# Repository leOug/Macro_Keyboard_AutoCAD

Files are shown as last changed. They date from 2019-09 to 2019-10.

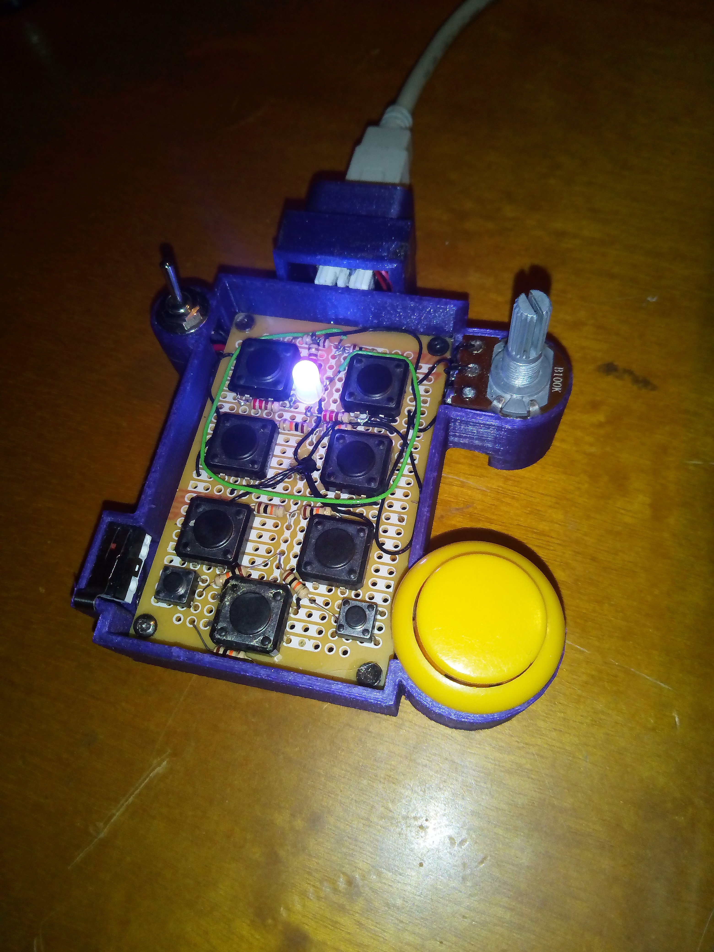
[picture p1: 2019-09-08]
Images/IMG_20190908_190952.jpg

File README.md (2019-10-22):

# Macro_Keyboard_AutoCAD
This is a shortcuts/macro keyboard intended for AutoCAD.

It can be expanded in order to be used with other programs.
I use an Arduino Leonardo Pro Micro ATmega32U4 5V 16MHz with the Keyboard.h library,
in order to send phrases (AutoCAD commands) and press Enter (KEY_RETURN) after a few miliseconds.

Also there is an RGB LED for indicating purposes. The LED can be substitcuted for three extra buttons or potentiometers although
it is rather usefull as it is.

The buttons were chosen for aesthetic and practical purposes. The Arcade button and the Microswitch were chosen for their clickiness
while the toggle switch (selector) is a three terminal one so that is has two modes of operation.

Each Button is connected to GND through a 10K Resistor and to a numbered PIN of the arduino
The toggle switch has three terminals, the left is connected to GND of the Arduino directly, the middle one is connected to a 
numbered arduino PIN and the right one is connected to VCC of the Arduino.

Materials Used:

* 1 x Arduino Leonardo Pro Micro ATmega32U4 5V 16MHz

* 1 x Toggle Switch SPDT ON-ON Mini

* 1 x Arcade Push Button Mini 27mm

* 1 x Microswitch Mini SPDT ON-(ON) - with Roller Simulation (the ones used in 3D printers and CNC machines)

* 2 x Tactile Switch 6x6mm 5mm 4pins

* 7 x Tactile Switch 12x12mm 4.3mm

* 1 x B100K Potentiometer

* 12 x 10KΩhm Resistors for the buttons

* 3 x 220Ωhm Resistors for the LED

* 1 x male micro USB header

* 1 x Female USB type B header

* 1 x perf board

* 4 x M.2 screws

* Super Glue

* Nail Polish for basic water resistance

* Some length of wire

I designed the casing according to the dimensions of the buttons and a vague notion of ergonomics.

You are free to use the design and the code for personal non-commercial usage.

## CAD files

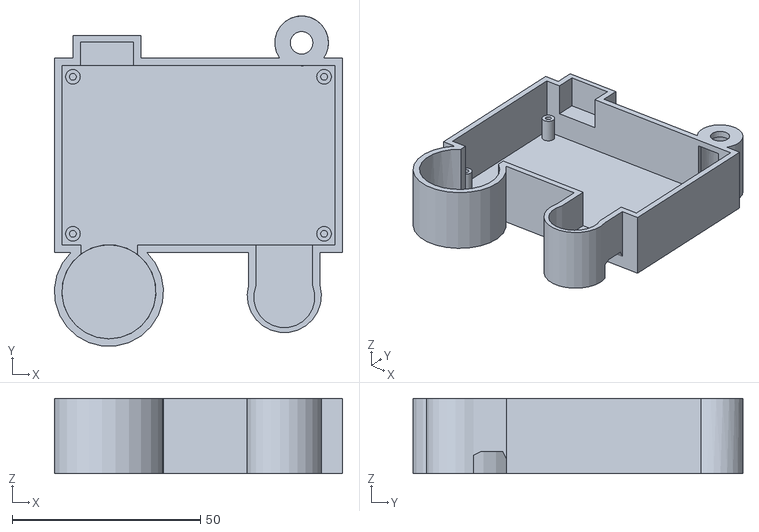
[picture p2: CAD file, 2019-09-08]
CAD/Keyboard.stl
76.5 x 87.6 x 20.0

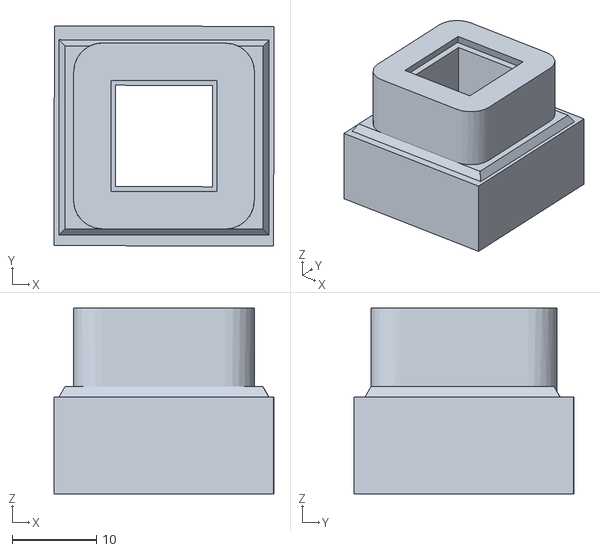
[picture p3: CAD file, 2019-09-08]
CAD/USB.stl
26.0 x 26.0 x 22.0

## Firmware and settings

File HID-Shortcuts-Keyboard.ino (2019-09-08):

#include "Keyboard.h"

#define BUTTON_1 3
#define BUTTON_2 4
#define BUTTON_3 5
#define BUTTON_4 6
#define BUTTON_5 7
#define BUTTON_6 10
#define BUTTON_7 14
#define BUTTON_8 15
#define BUTTON_9 16
#define BUTTON_10 2
#define BUTTON_11 8
int POTENTIOMETER_1 = A0;
int potentiometer_value;
#define SELECTOR_A1 A1
int selector_switch_value = 0; //The selector switch controls the functions of the arcade and the 3d printer buttons

int state = 1; // The initial state of the buttons

// 3 LED pins for the RGB LED, used as a visual indicator
#define LED_1 9
#define LED_2 A2
#define LED_3 A3

void setup()
{
  Serial.begin(9600); // Beging Serial Comunication
  //Define the pinMode for each pin.
  pinMode(2, INPUT);
  pinMode(3, INPUT);
  pinMode(4, INPUT);
  pinMode(5, INPUT);
  pinMode(6, INPUT);
  pinMode(7, INPUT);
  pinMode(8, INPUT);
  pinMode(10, INPUT);
  pinMode(14, INPUT);
  pinMode(15, INPUT);
  pinMode(16, INPUT);
  pinMode(A0, INPUT);
  pinMode(A1, INPUT);
  pinMode(9, OUTPUT);
  pinMode(A2, OUTPUT);
  pinMode(A3, OUTPUT);
  
  

  //Sets the value of the pin on start up.
 
  digitalWrite(BUTTON_1, HIGH);
  digitalWrite(BUTTON_2, HIGH);
  digitalWrite(BUTTON_3, HIGH);
  digitalWrite(BUTTON_4, HIGH);
  digitalWrite(BUTTON_5, HIGH);
  digitalWrite(BUTTON_6, HIGH);
  digitalWrite(BUTTON_7, HIGH);
  digitalWrite(BUTTON_8, HIGH);
  digitalWrite(BUTTON_9, HIGH);
  digitalWrite(POTENTIOMETER_1, HIGH);
  digitalWrite(BUTTON_10, HIGH);
  digitalWrite(BUTTON_11, HIGH);
  digitalWrite(LED_1, LOW);
  digitalWrite(LED_2, LOW);
  digitalWrite(LED_3, LOW);
  
  Keyboard.begin(); //Turns the keyboard input on.
  delay(200); //Wait before continuing on with the code.

}

void loop()

{
  
selector_switch_value = analogRead(SELECTOR_A1);
// If the button is pressed the state variable changes indicating a push
  state = digitalRead(BUTTON_8);
  // The selector switch is treated a potentiometer with two values, 0 and maximum
  // So i put a check for a median value to indicate the open and closing of the switch
  if(state != 1 && selector_switch_value < 500)
  {
    Keyboard.press(KEY_ESC);
    digitalWrite(LED_1, HIGH);
    delay(200);
    digitalWrite(LED_1, LOW);
    delay(50);
    Keyboard.releaseAll();
  }
  else if (state != 1 && selector_switch_value > 500)
  {
    Keyboard.print("qsave");
    digitalWrite(LED_3, HIGH);
    delay(200);
    Keyboard.press(KEY_RETURN);
    digitalWrite(LED_3, LOW);
    delay(50);
    Keyboard.releaseAll();
  }
 state = digitalRead(BUTTON_11);
  if(state != 1 && selector_switch_value < 550)
  {
    Keyboard.press(KEY_RETURN);
    Keyboard.releaseAll();
    digitalWrite(LED_3, HIGH);
    delay(200);
    digitalWrite(LED_3, LOW);
    delay(50);
    ;
  }
  else if (state != 1 && selector_switch_value > 500)
  {
    delay(200);
    Keyboard.press(KEY_DELETE);
    //Keyboard.press(KEY_LEFT_SHIFT);
    //Keyboard.press(KEY_LEFT_GUI);
   digitalWrite(LED_2,HIGH);
    //Keyboard.press(KEY_RETURN);
    Keyboard.releaseAll();
    digitalWrite(LED_2, LOW);
  }
//BEGIN FIRST PRESET
  potentiometer_value = analogRead(POTENTIOMETER_1);
  // The actual potentiometer is used to change between the presets.
  //By reading the potentiometer value (between 15 and 1023 for the B100k) i create 5 distinct "zones"
  //For each zone the 9 push buttons are assigned a function.
  //When the potentiometer is within the boundaries of the assigned zone, the LED changes colour
  if (potentiometer_value < 350 && potentiometer_value > 0) {
  //When the potentiometer is within the boundaries of the assigned zone, the LED changes colour
  digitalWrite(LED_2, LOW);
  digitalWrite(LED_3, HIGH);
  digitalWrite(LED_1, LOW);
  
  state = digitalRead(BUTTON_1);
  if(state != 1 && potentiometer_value < 350 && potentiometer_value>0)
  //FIRST PRESET
  {
  
    Keyboard.print("startcenter");
    delay(100);
    Keyboard.releaseAll();
    Keyboard.print("direction");
    Keyboard.releaseAll();
    delay(50);
    Keyboard.print("arc");
    delay(50);
    Keyboard.press(KEY_RETURN);
    delay(100);
    Keyboard.releaseAll();
  }
//FIRST PRESET
  state = digitalRead(BUTTON_2);
  if(state != 1 && potentiometer_value < 350 && potentiometer_value>0)
  {
    Keyboard.print("circle"); 
    delay(200);
    Keyboard.press(KEY_RETURN);
    delay(200);
    Keyboard.releaseAll();
  }
//FIRST PRESET

  state = digitalRead(BUTTON_3);
  if(state != 1 && potentiometer_value < 350 && potentiometer_value>0)
  {
    Keyboard.print("rectangle"); 
    delay(200);
    Keyboard.releaseAll();
    delay(300);
    Keyboard.press(KEY_RETURN);
    Keyboard.releaseAll();
    
  }
//FIRST PRESET

  state = digitalRead(BUTTON_4);
  if(state != 1 && potentiometer_value < 350 && potentiometer_value>0)
  {
    delay(100);
    Keyboard.print("scale"); 
    Keyboard.press(KEY_RETURN);
    delay(200);
    Keyboard.releaseAll();
  }
//FIRST PRESET

  state = digitalRead(BUTTON_5);
  if(state != 1 && potentiometer_value < 350 && potentiometer_value>0)
  {
    Keyboard.print("polygon"); 
    Keyboard.press(KEY_RETURN);
    delay(200);
    Keyboard.releaseAll();
  }
//FIRST PRESET

  state = digitalRead(BUTTON_6);
  if(state != 1 && potentiometer_value < 350 && potentiometer_value>0)
  {
    Keyboard.print("copy"); 
    Keyboard.press(KEY_RETURN); 
    delay(200);
    Keyboard.releaseAll();
  }
//FIRST PRESET

  state = digitalRead(BUTTON_7);
  if(state != 1 && potentiometer_value < 350 && potentiometer_value>0)
  {
    Keyboard.print("move");
    Keyboard.press(KEY_RETURN);
    delay(200);
    Keyboard.releaseAll();
  }
//FIRST PRESET

  state = digitalRead(BUTTON_10);
  if(state != 1 && potentiometer_value < 350 && potentiometer_value>0)
  {
    Keyboard.print("line"); 
    Keyboard.press(KEY_RETURN);
    delay(200);
    Keyboard.releaseAll();
  }
//FIRST PRESET

  state = digitalRead(BUTTON_9);
  if(state != 1 && potentiometer_value < 350 && potentiometer_value>0)
  {
     Keyboard.print("default");
    delay(100);
    Keyboard.print("gizmo");
    delay(100);
    Keyboard.press(KEY_RETURN);
    delay(300);
    Keyboard.releaseAll();
    Keyboard.press('0');
    delay(50);
    Keyboard.press(KEY_RETURN);
    Keyboard.releaseAll();
  }
  
//END OF FIRST PRESET
  }
//BEGIN SECOND PRESET 
  else if (potentiometer_value < 600 && potentiometer_value>401) {

  digitalWrite(LED_2, HIGH);
  digitalWrite(LED_3, LOW);
  digitalWrite(LED_1, LOW);
  
  state = digitalRead(BUTTON_1);
  if(state != 1 && potentiometer_value < 600 && potentiometer_value>401)
//SECOND PRESET   
  {
    Keyboard.print("join");
    delay(100);
    Keyboard.releaseAll();
    Keyboard.press(KEY_RETURN);
    delay(200);
    Keyboard.releaseAll();
  }
//SECOND PRESET   

  state = digitalRead(BUTTON_2);
  if(state != 1 && potentiometer_value < 600 && potentiometer_value>401)
  {
    Keyboard.print("array"); 
    delay(200);
    Keyboard.press(KEY_RETURN);
    delay(200);
    Keyboard.releaseAll();
  }
//SECOND PRESET  
  state = digitalRead(BUTTON_3);
 if(state != 1 && potentiometer_value < 600 && potentiometer_value>401)
  {
    Keyboard.print("trim"); 
    delay(200);
    Keyboard.releaseAll();
    delay(100);
    Keyboard.press(KEY_RETURN);
    Keyboard.releaseAll();
    
  }
//SECOND PRESET  
  state = digitalRead(BUTTON_4);
 if(state != 1 && potentiometer_value < 600 && potentiometer_value>401)
  {
    Keyboard.print("pedit"); 
    delay(300);
    Keyboard.press(KEY_RETURN); 
    delay(200);
    Keyboard.releaseAll();
  }
//SECOND PRESET  
  state = digitalRead(BUTTON_5);
  if(state != 1 && potentiometer_value < 600 && potentiometer_value>401)
  {
    Keyboard.print("explode"); 
    Keyboard.press(KEY_RETURN);
    delay(200);
    Keyboard.releaseAll();
  }
//SECOND PRESET  
  state = digitalRead(BUTTON_6);
 if(state != 1 && potentiometer_value < 600 && potentiometer_value>401)
  {
    Keyboard.print("copy"); 
    Keyboard.press(KEY_RETURN); 
    delay(200);
    Keyboard.releaseAll();
  }
//SECOND PRESET  
  state = digitalRead(BUTTON_7);
  if(state != 1 && potentiometer_value < 600 && potentiometer_value>401)
  {
    Keyboard.print("move");
    Keyboard.press(KEY_RETURN);
    delay(200);
    Keyboard.releaseAll();
  }
//SECOND PRESET  
  state = digitalRead(BUTTON_10);
  if(state != 1 && potentiometer_value < 600 && potentiometer_value>401)
  {
    Keyboard.print("offset"); 
    Keyboard.press(KEY_RETURN);
    delay(200);
    Keyboard.releaseAll();
  }
//SECOND PRESET  
  state = digitalRead(BUTTON_9);
  if(state != 1 && potentiometer_value < 600 && potentiometer_value>401)
  {
    Keyboard.print("default");
    delay(100);
    Keyboard.print("gizmo");
    delay(100);
    Keyboard.press(KEY_RETURN);
    delay(300);
    Keyboard.releaseAll();
    Keyboard.press('1');
    delay(50);
    Keyboard.press(KEY_RETURN);
    Keyboard.releaseAll();
  }
  //END OF SECOND PRESET
  }
  //BEGIN THIRD PRESET
  else if (potentiometer_value < 800 && potentiometer_value > 601  ) {
   digitalWrite(LED_2,LOW);
  digitalWrite(LED_3, LOW);
  digitalWrite(LED_1, HIGH);
// THIRD PRESET
  state = digitalRead(BUTTON_1);
  if(state != 1 && potentiometer_value < 800 && potentiometer_value>601)
  
  {
    Keyboard.print("extrude");
    delay(100);
    Keyboard.press(KEY_RETURN);
    delay(200);
    Keyboard.releaseAll();
  }
// THIRD PRESET

  state = digitalRead(BUTTON_2);
 if(state != 1 && potentiometer_value < 800 && potentiometer_value>601)
  {
    delay(100);
    Keyboard.print("measuredistance"); 
    delay(200);
    Keyboard.press(KEY_RETURN);
    delay(200);
    Keyboard.releaseAll();
  }
// THIRD PRESET

  state = digitalRead(BUTTON_3);
  if(state != 1 && potentiometer_value < 800 && potentiometer_value>601)
  {
    Keyboard.print("cylinder"); 
    delay(200);
    Keyboard.press(KEY_RETURN);
    delay(200);
    Keyboard.releaseAll();
    
  }
// THIRD PRESET

  state = digitalRead(BUTTON_4);
  if(state != 1 && potentiometer_value < 800 && potentiometer_value>601)
  {
    Keyboard.print("sweep"); 
    delay(300);
    Keyboard.press(KEY_RETURN); 
    delay(200);
    Keyboard.releaseAll();
  }
// THIRD PRESET

  state = digitalRead(BUTTON_5);
  if(state != 1 && potentiometer_value < 800 && potentiometer_value>601)
  {
    
    Keyboard.print("presspull");
    delay(100); 
    Keyboard.press(KEY_RETURN);
    delay(200);
    Keyboard.releaseAll();
  }
// THIRD PRESET

  state = digitalRead(BUTTON_6);
  if(state != 1 && potentiometer_value < 800 && potentiometer_value>601)
  {
    Keyboard.print("copy"); 
    Keyboard.press(KEY_RETURN); 
    delay(200);
    Keyboard.releaseAll();
  }
// THIRD PRESET

  state = digitalRead(BUTTON_7);
  if(state != 1 && potentiometer_value < 800 && potentiometer_value>601)
  {
    Keyboard.print("move");
    Keyboard.press(KEY_RETURN);
    delay(200);
    Keyboard.releaseAll();
  }
// THIRD PRESET

  state = digitalRead(BUTTON_10);
  if(state != 1 && potentiometer_value < 800 && potentiometer_value>601)
  {
    Keyboard.print("box"); 
    Keyboard.press(KEY_RETURN);
    delay(200);
    Keyboard.releaseAll();
  }
// THIRD PRESET

  state = digitalRead(BUTTON_9);
  if(state != 1 && potentiometer_value < 800 && potentiometer_value>601)
  {
    Keyboard.print("default");
    delay(100);
    Keyboard.print("gizmo");
    delay(100);
    Keyboard.press(KEY_RETURN);
    delay(300);
    Keyboard.releaseAll();
    Keyboard.press('0');
    delay(50);
    Keyboard.press(KEY_RETURN);
    Keyboard.releaseAll();
  }
 
  }

  //BEGIN FOURTH PRESET 
  else if (potentiometer_value < 1000 && potentiometer_value > 801) {

  digitalWrite(LED_2, HIGH);
  digitalWrite(LED_3, HIGH);
  digitalWrite(LED_1, LOW);
  
  state = digitalRead(BUTTON_1);
  if(state != 1 && potentiometer_value < 1000 && potentiometer_value > 801)
  
  {
    
    Keyboard.print("union");
    delay(100);
    Keyboard.releaseAll();
    Keyboard.press(KEY_RETURN);
    delay(200);
    Keyboard.releaseAll();
  }
// FOURTH PRESET 
  state = digitalRead(BUTTON_2);
  if(state != 1 && potentiometer_value < 1000 && potentiometer_value > 801)
  {
    delay(100);
    Keyboard.print("measuredistance");
    delay(100);
    Keyboard.releaseAll();
    Keyboard.press(KEY_RETURN);
    delay(200);
    Keyboard.releaseAll();
  }
// FOURTH PRESET 

  state = digitalRead(BUTTON_3);
 if(state != 1 && potentiometer_value < 1000 && potentiometer_value > 801)
  {
     Keyboard.print("substract");
    delay(200);
    Keyboard.releaseAll();
  }
// FOURTH PRESET 

  state = digitalRead(BUTTON_4);
 if(state != 1 && potentiometer_value < 1000 && potentiometer_value > 801)
  {
    Keyboard.print("slice"); 
    delay(300);
    Keyboard.press(KEY_RETURN); 
    delay(200);
    Keyboard.releaseAll();
  }
// FOURTH PRESET 

  state = digitalRead(BUTTON_5);
  if(state != 1 && potentiometer_value < 1000 && potentiometer_value > 801)
  {
    Keyboard.print("filletedge"); 
    Keyboard.press(KEY_RETURN);
    delay(200);
    Keyboard.releaseAll();
  }
// FOURTH PRESET 

  state = digitalRead(BUTTON_6);
 if(state != 1 && potentiometer_value < 1000 && potentiometer_value > 801)
  {
    Keyboard.print("copy"); 
    Keyboard.press(KEY_RETURN); 
    delay(200);
    Keyboard.releaseAll();
  }
// FOURTH PRESET 

  state = digitalRead(BUTTON_7);
  if(state != 1 && potentiometer_value < 1000 && potentiometer_value > 801)
  {
    Keyboard.print("move");
    Keyboard.press(KEY_RETURN);
    delay(200);
    Keyboard.releaseAll();
  }
// FOURTH PRESET 

  state = digitalRead(BUTTON_10);
  if(state != 1 && potentiometer_value < 1000 && potentiometer_value > 801)
  {
    Keyboard.print("intersect"); 
    Keyboard.press(KEY_RETURN);
    delay(200);
    Keyboard.releaseAll();
  }
// FOURTH PRESET 

  state = digitalRead(BUTTON_9);
  if(state != 1 && potentiometer_value < 1000 && potentiometer_value > 801)
  {
    Keyboard.print("default");
    delay(100);
    Keyboard.print("gizmo");
    delay(100);
    Keyboard.press(KEY_RETURN);
    delay(300);
    Keyboard.releaseAll();
    Keyboard.press('1');
    delay(50);
    Keyboard.press(KEY_RETURN);
    Keyboard.releaseAll();
  }
  //END OF FOURTH PRESET
  
  } 

   //BEGIN FIFTH PRESET 
  else if (potentiometer_value <= 1023 && potentiometer_value > 1001) {

  digitalWrite(LED_2, LOW);
  digitalWrite(LED_3, HIGH);
  digitalWrite(LED_1, HIGH);
  
  state = digitalRead(BUTTON_1);
  if(state != 1 && potentiometer_value <= 1023 && potentiometer_value > 1001)
//FIFTH PRESET  
  {
    Keyboard.print("visual");
    delay(50);
    Keyboard.print("styles");
    delay(50);
    Keyboard.releaseAll();
    Keyboard.press(KEY_RETURN);
    delay(200);
    Keyboard.releaseAll();
  }
//FIFTH PRESET
  state = digitalRead(BUTTON_2);
  if(state != 1 && potentiometer_value <= 1023 && potentiometer_value > 1001)
  {
    Keyboard.print("measure"); 
    delay(200);
    Keyboard.print("distance");
    delay(200);
    Keyboard.press(KEY_RETURN);
    delay(200);
    Keyboard.releaseAll();
  }
//FIFTH PRESET
  state = digitalRead(BUTTON_3);
 if(state != 1 && potentiometer_value <= 1023 && potentiometer_value > 1001)
  {
    Keyboard.print("measure"); 
    delay(200);
    Keyboard.print("distance");
    delay(200);
    Keyboard.releaseAll();
    delay(100);
    Keyboard.press(KEY_RETURN);
    Keyboard.releaseAll();
    
  }
//FIFTH PRESET
  state = digitalRead(BUTTON_4);
 if(state != 1 && potentiometer_value <= 1023 && potentiometer_value > 1001)
  {
    Keyboard.print("align"); 
    delay(300);
    Keyboard.press(KEY_RETURN); 
    delay(200);
    Keyboard.releaseAll();
  }
//FIFTH PRESET
  state = digitalRead(BUTTON_5);
  if(state != 1 && potentiometer_value <= 1023 && potentiometer_value > 1001)
  {
    Keyboard.print("txtexp"); 
    Keyboard.press(KEY_RETURN);
    delay(200);
    Keyboard.releaseAll();
  }
//FIFTH PRESET
  state = digitalRead(BUTTON_6);
 if(state != 1 && potentiometer_value <= 1023 && potentiometer_value > 1001)
  {
    Keyboard.print("export"); 
    Keyboard.press(KEY_RETURN); 
    delay(200);
    Keyboard.releaseAll();
  }
//FIFTH PRESET
  state = digitalRead(BUTTON_7);
  if(state != 1 && potentiometer_value <= 1023 && potentiometer_value > 1001)
  {
    Keyboard.print("mtext");
    Keyboard.press(KEY_RETURN);
    delay(200);
    Keyboard.releaseAll();
  }
//FIFTH PRESET
  state = digitalRead(BUTTON_10);
  if(state != 1 && potentiometer_value <= 1023 && potentiometer_value > 1001)
  {
    Keyboard.print("visual");
    delay(50);
    Keyboard.print("styles");
    delay(50);
    Keyboard.print("close");
    delay(100);
    Keyboard.press(KEY_RETURN);
    Keyboard.releaseAll();
  }
//FIFTH PRESET
  state = digitalRead(BUTTON_9);
  if(state != 1 && potentiometer_value <= 1023 && potentiometer_value > 1001)
  {
    Keyboard.print("default");
    delay(100);
    Keyboard.print("gizmo");
    delay(100);
    Keyboard.press(KEY_RETURN);
    delay(300);
    Keyboard.releaseAll();
    Keyboard.press('0');
    delay(50);
    Keyboard.press(KEY_RETURN);
    Keyboard.releaseAll();
  }
  //END OF FIFTH PRESET
  
  }
}

  
